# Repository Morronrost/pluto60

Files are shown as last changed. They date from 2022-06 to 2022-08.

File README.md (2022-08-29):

# PLUTO60
The PLUTO60 is a 60% PCB designed for Space Invader switches. The MCU Board is the Xiao RP2040 from Seeed.

## Features
- Space Invader switches (Hitek 725)
- PRK Firmware
- Japanese Duplex Matrix
- USB C
- GH60 Compatible 
- Confirmed Working (Newest revision has not been tested, proceed at your own risk)
## Layout
Due to pin limitations, the PLUTO60 has a fixed ISO layout without split left-shift. It can however be used in an winkeyless configuration if desired.

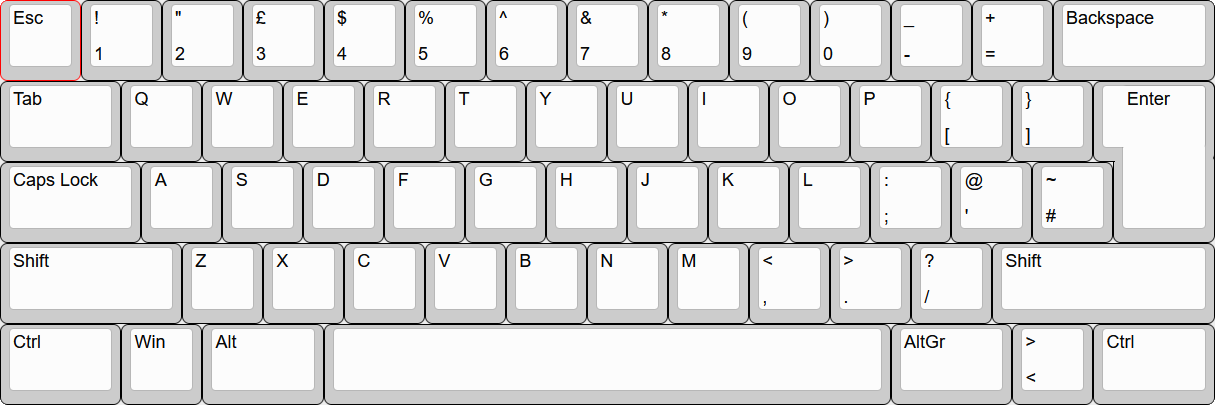
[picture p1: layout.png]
Layout Image


## Instructions

1. Install PRK and place the keymap on the MCU
2. Solder all the switches in place
3. Clip the legs of the "Esc" and "1" switches that are under the MCU
4. Solder the MCU

# Custom keymap

Instructions on how to make a custom keymap can be found on the [PRK Firmware wiki](https://github.com/picoruby/prk_firmware/wiki/).

## Credits
- Engicoder & Gvalch'ca for the Hitek 725 footprints
- amtra5 & _spindle for GH60 template footprints
- Inozenz for bringing Space Invaders to the masses
- Hasumikin for PRK Firmware
- Seeed for the free PCBs

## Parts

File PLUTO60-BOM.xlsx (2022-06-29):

Designator | MPN/Seeed SKU | Qty | Link
D21,D55,D20,D33,D26,D23,D43,D60,D5,D8,D2,D37,D52,D29,D22,D57,D19,D28,D16,D39,D31,D42,D30,D54,D35,D25,D1,D50,D41,D51,D27,D10,D53,D6,D38,D17,D12,D44,D45,D9,D47,D3,D24,D13,D49,D36,D59,D14,D46,D56,D18,D34,D40,D7,D4,D15,D32,D48,D58,D11 | 304010007 | 60 | https://www.seeedstudio.com/opl.html
M1 | 102010428 | 1 | https://www.seeedstudio.com/XIAO-RP2040-v1-0-p-5026.html

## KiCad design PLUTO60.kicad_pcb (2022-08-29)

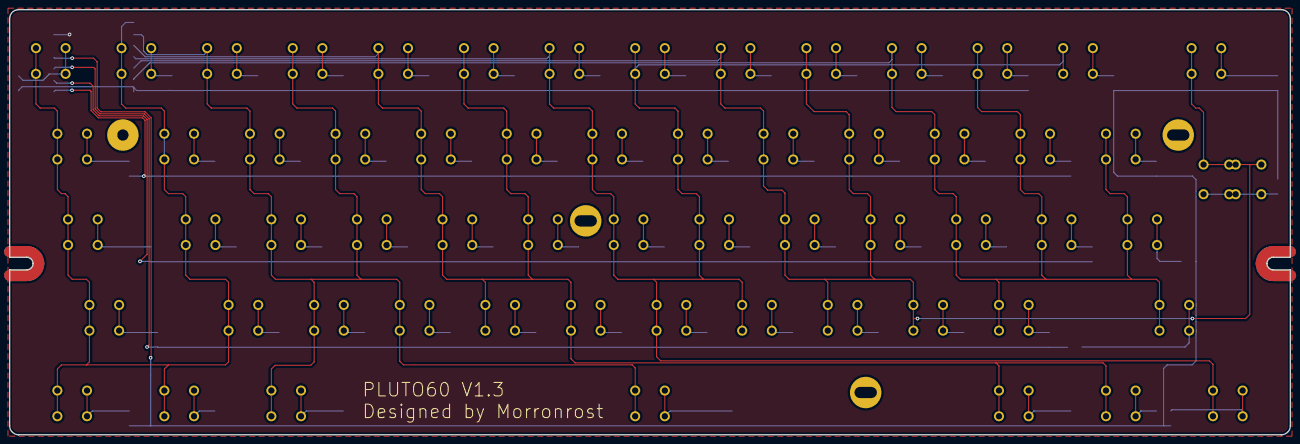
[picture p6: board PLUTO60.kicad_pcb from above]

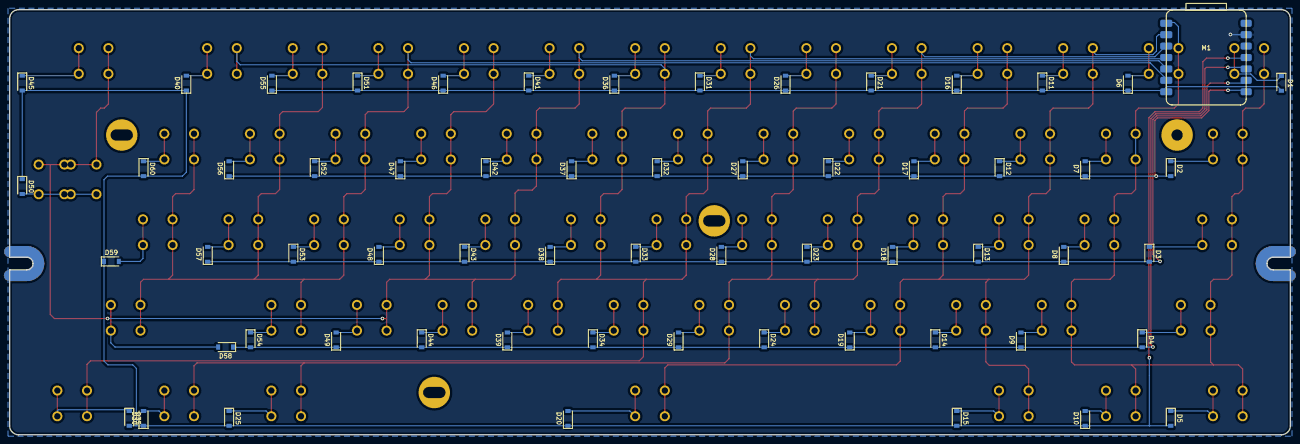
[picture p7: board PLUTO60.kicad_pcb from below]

Board: 2 copper layers, 285.0 x 94.6 mm, 121 parts (61 on the bottom side), 71 nets.

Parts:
D1, D2, D3, D4, D5, D6, D7, D8, D9, D10, D11, D12, D13, D14, D15, D16, D17, D18, D19, D20, D21, D22, D23, D24, D25, D26, D27, D28, D29, D30, D31, D32, D33, D34, D35, D36, D37, D38, D39, D40, D41, D42, D43, D44, D45, D46, D47, D48, D49, D50, D51, D52, D53, D54, D55, D56, D57, D58, D59, D60: D_Small; D_SOD-123
M1: XIAO-RP2040
MX1, MX6, MX7, MX8, MX9, MX10, MX11, MX12, MX13, MX14, MX16, MX17, MX18, MX19, MX21, MX22, MX23, MX24, MX26, MX27, MX28, MX29, MX30, MX31, MX32, MX33, MX34, MX36, MX37, MX38, MX39, MX40, MX41, MX42, MX43, MX44, MX46, MX47, MX48, MX49, MX51, MX52, MX53, MX54, MX55, MX56, MX57, MX58, MX60: MX-NoLED; Hitek725-1U
MX2, MX5, MX15, MX25, MX35: MX-NoLED; Hitek725-1.5U
MX3: MX-NoLED; Hitek725-1.75U
MX4: MX-NoLED; Hitek725-2.25U
MX20: MX-NoLED; Hitek725-7U
MX45: MX-NoLED; Hitek725-2U
MX50: MX-NoLED; Hitek725-BigAssEnter-separated-pins
MX59: MX-NoLED; Hitek725-2.75U

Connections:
COL0: M1.1 (D0), MX1.1 (COL), MX2.1 (COL), MX3.1 (COL), MX4.1 (COL), MX5.1 (COL), MX6.1 (COL), MX7.1 (COL), MX8.1 (COL), MX9.1 (COL), MX10.1 (COL)
COL1: M1.2 (D1), MX11.1 (COL), MX12.1 (COL), MX13.1 (COL), MX14.1 (COL), MX15.1 (COL), MX16.1 (COL), MX17.1 (COL), MX18.1 (COL), MX19.1 (COL), MX20.1 (COL)
COL2: M1.3 (D2), MX21.1 (COL), MX22.1 (COL), MX23.1 (COL), MX24.1 (COL), MX25.1 (COL), MX26.1 (COL), MX27.1 (COL), MX28.1 (COL), MX29.1 (COL), MX30.1 (COL)
COL3: M1.4 (D3), MX31.1 (COL), MX32.1 (COL), MX33.1 (COL), MX34.1 (COL), MX35.1 (COL), MX36.1 (COL), MX37.1 (COL), MX38.1 (COL), MX39.1 (COL), MX40.1 (COL)
COL4: M1.5 (D4), MX41.1 (COL), MX42.1 (COL), MX43.1 (COL), MX44.1 (COL), MX45.1 (COL), MX46.1 (COL), MX47.1 (COL), MX48.1 (COL), MX49.1 (COL), MX50.1 (COL)
COL5: M1.6 (D5), MX51.1 (COL), MX52.1 (COL), MX53.1 (COL), MX54.1 (COL), MX55.1 (COL), MX56.1 (COL), MX57.1 (COL), MX58.1 (COL), MX59.1 (COL), MX60.1 (COL)
unnamed: D1.1 (K), MX1.2 (ROW)
unnamed: D2.1 (K), MX2.2 (ROW)
unnamed: D3.1 (K), MX3.2 (ROW)
unnamed: D4.1 (K), MX4.2 (ROW)
unnamed: D5.1 (K), MX5.2 (ROW)
unnamed: D6.2 (A), MX6.2 (ROW)
unnamed: D7.2 (A), MX7.2 (ROW)
unnamed: D8.2 (A), MX8.2 (ROW)
unnamed: D9.2 (A), MX9.2 (ROW)
unnamed: D10.2 (A), MX10.2 (ROW)
unnamed: D11.1 (K), MX11.2 (ROW)
unnamed: D12.1 (K), MX12.2 (ROW)
unnamed: D13.1 (K), MX13.2 (ROW)
unnamed: D14.1 (K), MX14.2 (ROW)
unnamed: D15.1 (K), MX15.2 (ROW)
unnamed: D16.2 (A), MX16.2 (ROW)
unnamed: D17.2 (A), MX17.2 (ROW)
unnamed: D18.2 (A), MX18.2 (ROW)
unnamed: D19.2 (A), MX19.2 (ROW)
unnamed: D20.2 (A), MX20.2 (ROW)
unnamed: D21.1 (K), MX21.2 (ROW)
unnamed: D22.1 (K), MX22.2 (ROW)
unnamed: D23.1 (K), MX23.2 (ROW)
unnamed: D24.1 (K), MX24.2 (ROW)
unnamed: D25.1 (K), MX25.2 (ROW)
unnamed: D26.2 (A), MX26.2 (ROW)
unnamed: D27.2 (A), MX27.2 (ROW)
unnamed: D28.2 (A), MX28.2 (ROW)
unnamed: D29.2 (A), MX29.2 (ROW)
unnamed: D30.2 (A), MX30.2 (ROW)
unnamed: D31.1 (K), MX31.2 (ROW)
unnamed: D32.1 (K), MX32.2 (ROW)
unnamed: D33.1 (K), MX33.2 (ROW)
unnamed: D34.1 (K), MX34.2 (ROW)
unnamed: D35.1 (K), MX35.2 (ROW)
unnamed: D36.2 (A), MX36.2 (ROW)
unnamed: D37.2 (A), MX37.2 (ROW)
unnamed: D38.2 (A), MX38.2 (ROW)
unnamed: D39.2 (A), MX39.2 (ROW)
unnamed: D40.2 (A), MX40.2 (ROW)
unnamed: D41.1 (K), MX41.2 (ROW)
unnamed: D42.1 (K), MX42.2 (ROW)
unnamed: D43.1 (K), MX43.2 (ROW)
unnamed: D44.1 (K), MX44.2 (ROW)
unnamed: D45.1 (K), MX45.2 (ROW)
unnamed: D46.2 (A), MX46.2 (ROW)
unnamed: D47.2 (A), MX47.2 (ROW)
unnamed: D48.2 (A), MX48.2 (ROW)
unnamed: D49.2 (A), MX49.2 (ROW)
unnamed: D50.2 (A), MX50.2 (ROW)
unnamed: D51.1 (K), MX51.2 (ROW)
unnamed: D52.1 (K), MX52.2 (ROW)
unnamed: D53.1 (K), MX53.2 (ROW)
unnamed: D54.1 (K), MX54.2 (ROW)
unnamed: D55.2 (A), MX56.2 (ROW)
unnamed: D56.2 (A), MX57.2 (ROW)
unnamed: D57.2 (A), MX58.2 (ROW)
unnamed: D58.2 (A), MX59.2 (ROW)
unnamed: D59.2 (A), MX60.2 (ROW)
unnamed: D60.1 (K), MX55.2 (ROW)
ROW0: D1.2 (A), D6.1 (K), D11.2 (A), D16.1 (K), D21.2 (A), D26.1 (K), D31.2 (A), D36.1 (K), D41.2 (A), D46.1 (K), D51.2 (A), D55.1 (K), M1.7 (D6)
ROW1: D2.2 (A), D7.1 (K), D12.2 (A), D17.1 (K), D22.2 (A), D27.1 (K), D32.2 (A), D37.1 (K), D42.2 (A), D47.1 (K), D52.2 (A), D56.1 (K), M1.8 (D7)
ROW2: D3.2 (A), D8.1 (K), D13.2 (A), D18.1 (K), D23.2 (A), D28.1 (K), D33.2 (A), D38.1 (K), D43.2 (A), D48.1 (K), D53.2 (A), D57.1 (K), M1.9 (D8)
ROW3: D4.2 (A), D9.1 (K), D14.2 (A), D19.1 (K), D24.2 (A), D29.1 (K), D34.2 (A), D39.1 (K), D44.2 (A), D49.1 (K), D54.2 (A), D58.1 (K), M1.10 (D9)
ROW4: D5.2 (A), D10.1 (K), D15.2 (A), D20.1 (K), D25.2 (A), D30.1 (K), D35.2 (A), D40.1 (K), D45.2 (A), D50.1 (K), D59.1 (K), D60.2 (A), M1.11 (D10)

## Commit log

2022-07-07 Cleaned up repository
    [PLUTO60-BOM.xlsx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]
2022-07-07 Put files at repository root
    [PLUTO60-BOM.xlsx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]
2022-08-29 Corrected MCU placement & tidied routing
    [PLUTO60-B_Cu.gbl, PLUTO60-B_Mask.gbs, PLUTO60-B_Silkscreen.gbo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]
